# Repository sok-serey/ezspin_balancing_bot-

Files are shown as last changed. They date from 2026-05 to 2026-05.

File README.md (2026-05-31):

# EzSpin Balancing Bot 🤖⚙️

<p align="center">
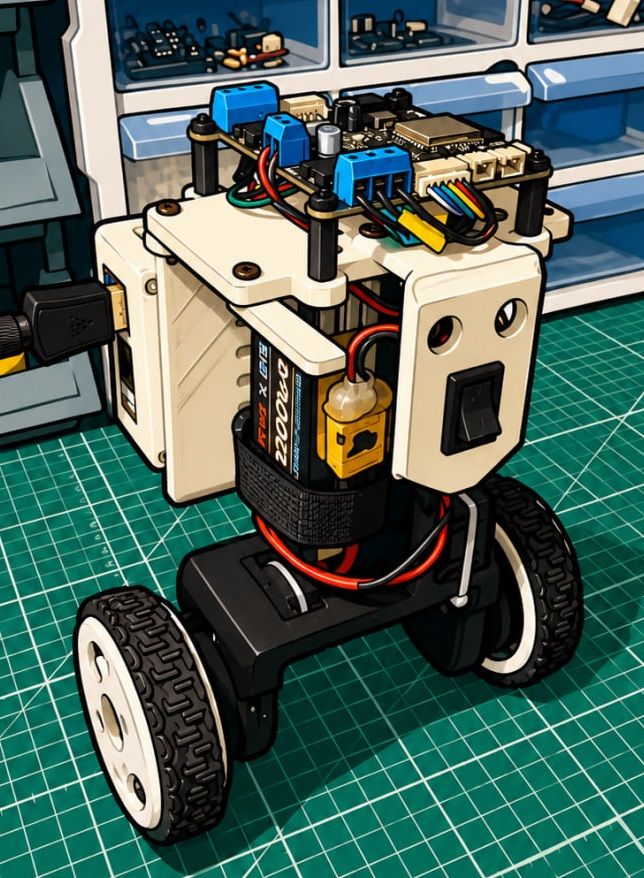
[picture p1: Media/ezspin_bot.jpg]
EzSpin Balancing Bot
  
</p>

## Overview
EzSpin Balancing Bot is a two-wheel self-balancing mobile robot powered by a custom BLDC motor driver.  
The system is designed to control gimbal-type BLDC motors equipped with magnetic encoders via SPI communication.
The custom motor driver also integrates an onboard IMU, providing real-time feedback for closed-loop control and robot stabilization.

---

## Features

- Two-wheel self-balancing mobile platform  
- Onboard IMU sensor for attitude estimation  
- Cascaded PID control architecture  
- BLDC motor control using the SimpleFOC library  
- CAN communication protocol support  
- Supports position, velocity, and torque control modes  
- Multi-platform support: ROS 2, Arduino IDE, MATLAB/Simulink  
- Expandable for autonomous navigation and AI applications  

---

## Robot Overview

### Control Architecture

The EzSpin Balancing Bot maintains stability using a cascade PID control architecture, consisting of an outer velocity control loop and an inner position control loop. The system can be further extended by integrating an Orange Pi 5B running ROS 2, enabling advanced high-level control and communication. A web-based GUI can be developed to send real-time velocity commands, which are then transmitted from the ROS 2 system to the EzSpin controller via the CAN bus protocol for robot motion control and balancing.

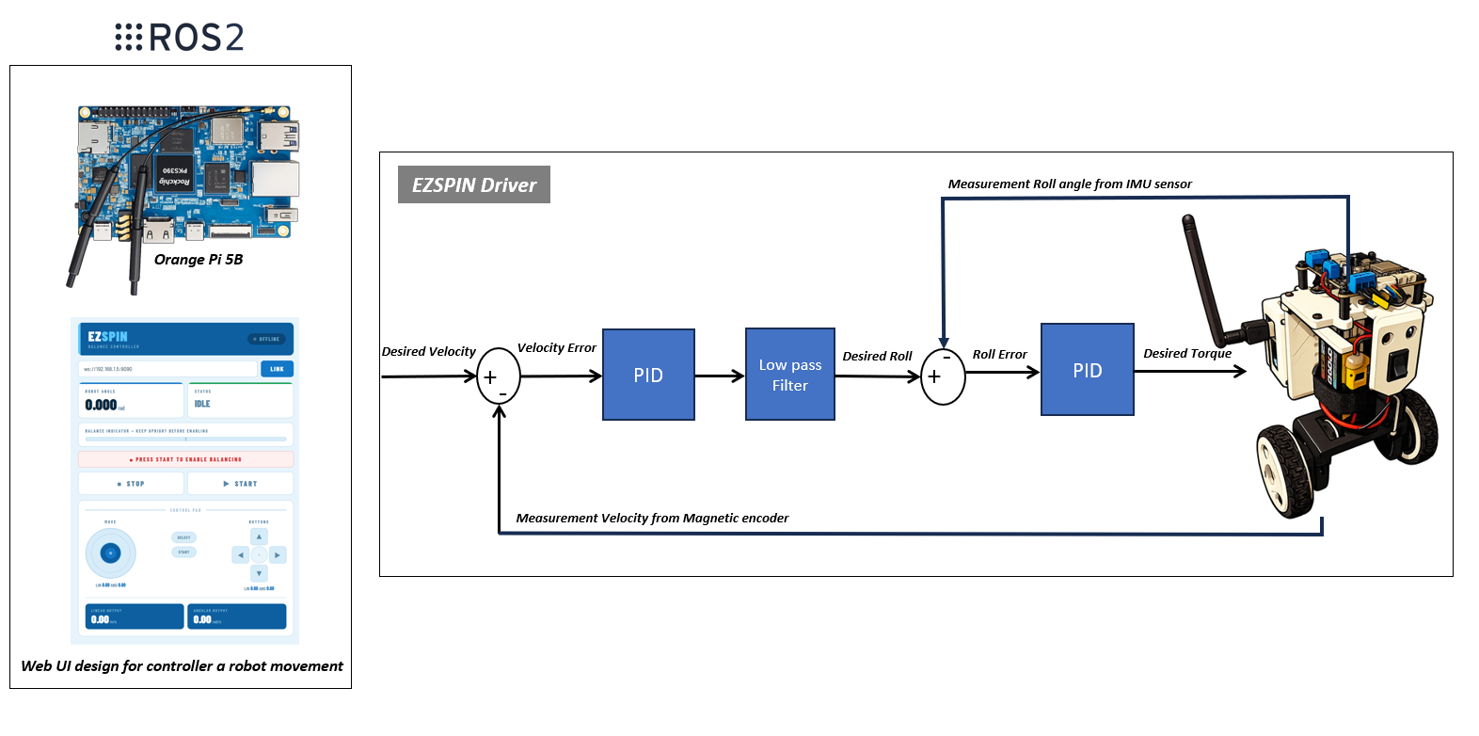
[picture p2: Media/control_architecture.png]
Control Architecture


---

### System Architecture

The EzSpin controller is capable of controlling up to two motors simultaneously while utilizing onboard IMU feedback for real-time stabilization and motion control. The EzSpin board is designed as a ready-to-use solution that supports position, velocity, and torque control modes through both Serial and CAN Bus communication interfaces.

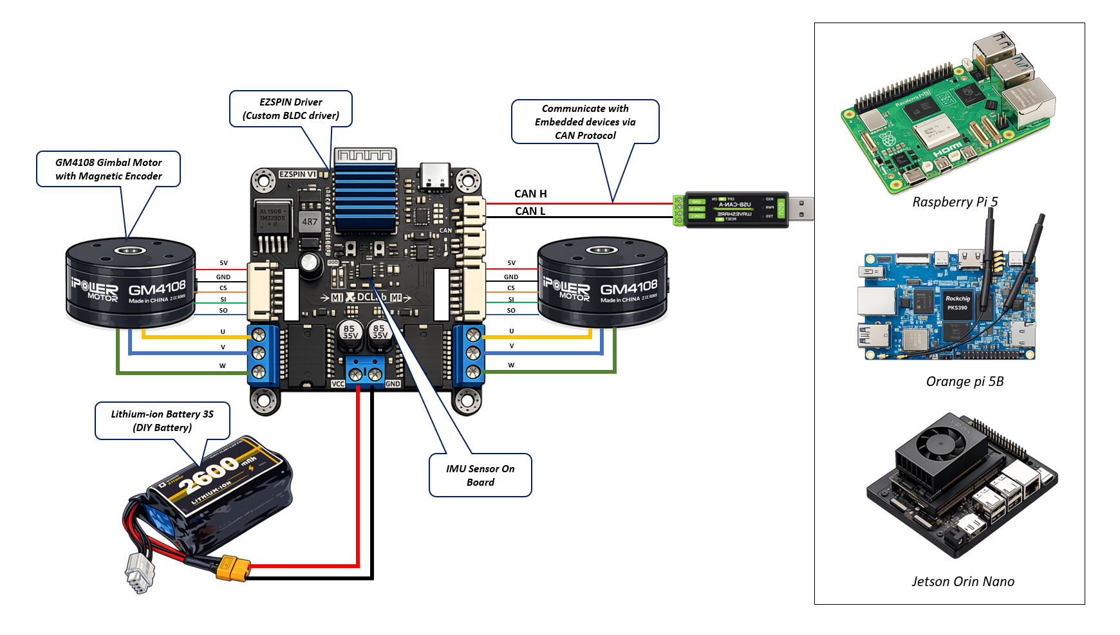
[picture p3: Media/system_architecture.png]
System Architecture


---

### Web GUI

A web-based GUI is developed for real-time control of the EzSpin Bot by sending velocity commands to the robot. The commands are transmitted through the ROS 2 system and communicated to the EzSpin controller via the CAN Bus protocol, enabling responsive and interactive robot operation.

<p align="center">
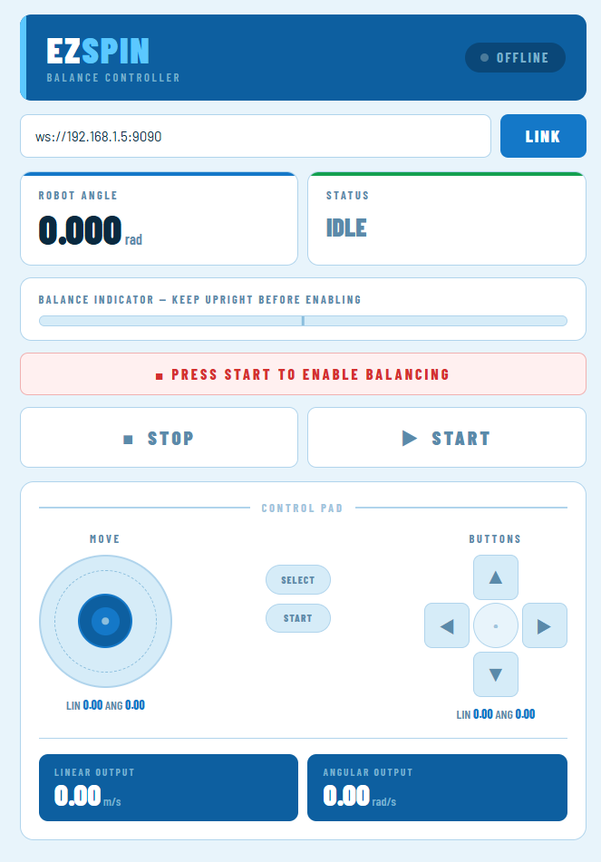
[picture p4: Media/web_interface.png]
Web GUI
  
</p>

## Hardware

### Main Components

| Component | Description |
|---|---|
| MCU | ESP32 |
| IMU | MPU6050 |
| Motor Driver | EzSpin Custom BLDC Driver |
| Motors | GM4108 with Magnetic Encoder |
| Battery | EzSpin DIY Li-ion Battery (3S) |
| Communication  | CAN Bus |

---

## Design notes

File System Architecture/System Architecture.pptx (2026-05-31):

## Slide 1

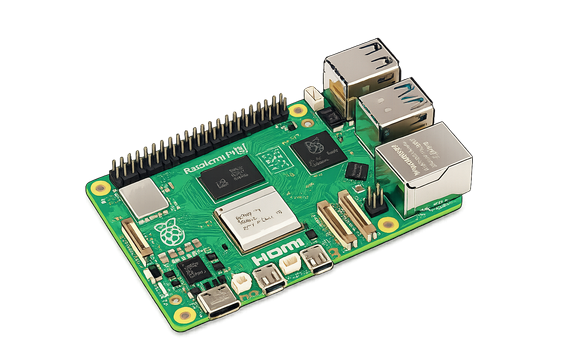
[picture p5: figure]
Cartoon style Raspberry Pi 5 board

Raspberry Pi 5

Orange pi 5B

Jetson Orin Nano

EZSPIN Driver (Custom BLDC driver)

Communicate with Embedded devices via
CAN Protocol

GM4108 Gimbal Motor with Magnetic Encoder

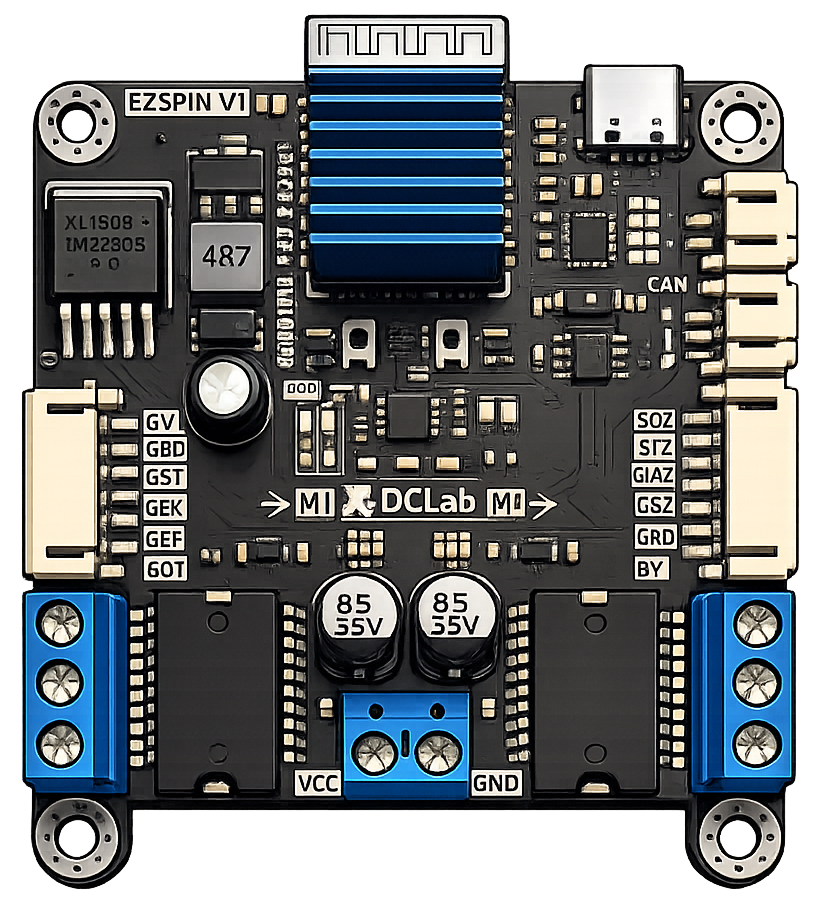
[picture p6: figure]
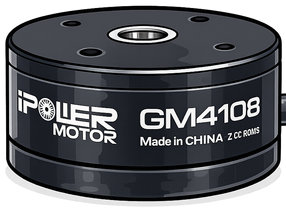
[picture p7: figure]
Cartoon style iPOWER MOTOR GM4108

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
CAN H

CAN L

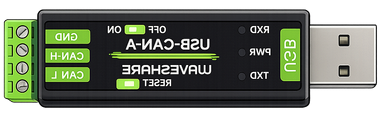
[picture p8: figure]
Cartoon style USB-CAN-A adapter
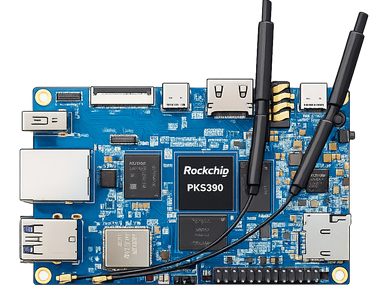
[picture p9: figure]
Cartoon style Rockchip RK3399 development board
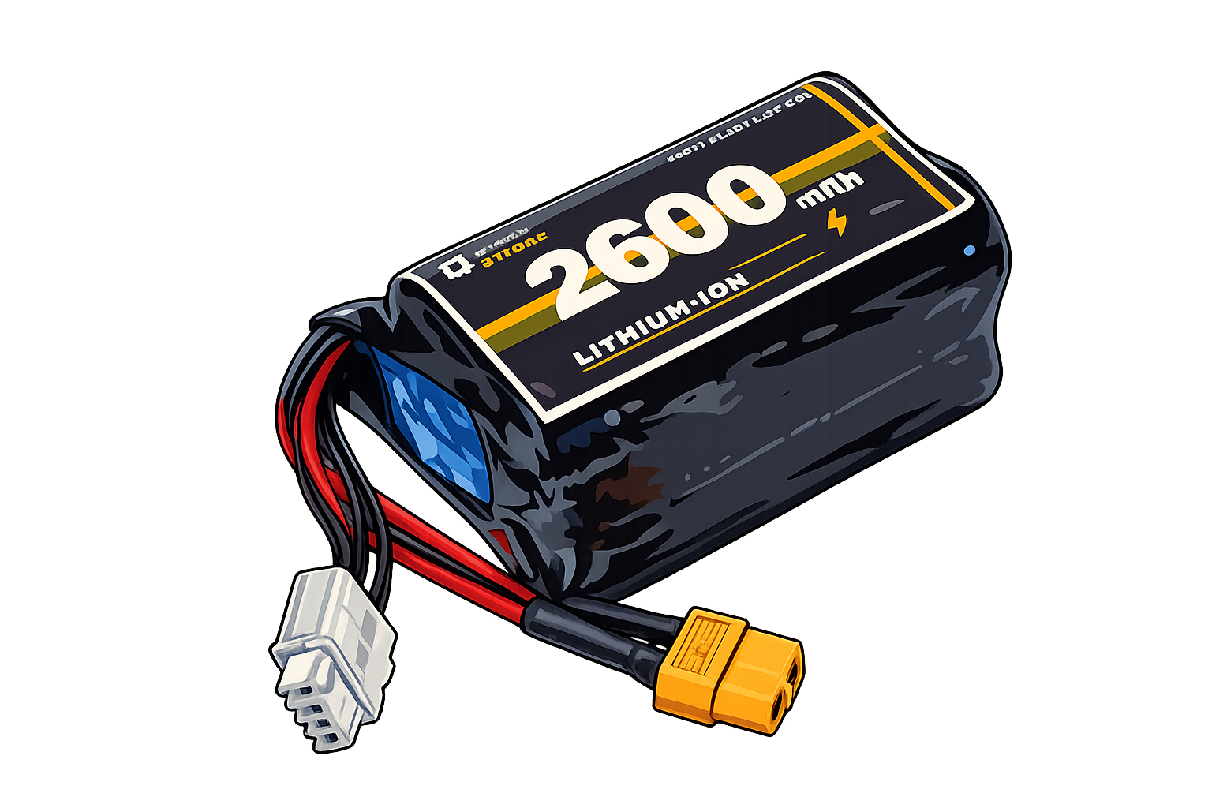
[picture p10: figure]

Lithium-ion Battery 3S
(DIY Battery)

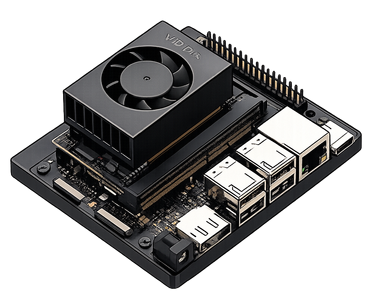
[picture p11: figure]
Cartoon style NVIDIA Jetson Nano board

IMU Sensor On Board

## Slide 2

Web UI design for controller a robot movement

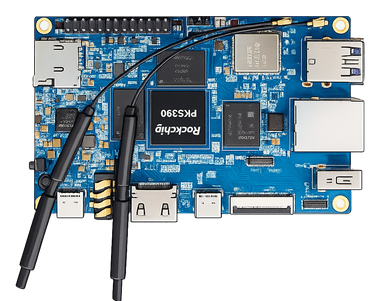
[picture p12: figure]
Cartoon style Rockchip RK3399 development board

Measurement Roll angle from IMU sensor

Desired Velocity

+

Velocity Error

PID

Low pass Filter

Desired Roll

+

Roll Error

PID

Desired Torque

Measurement Velocity from Magnetic encoder

EZSPIN Driver

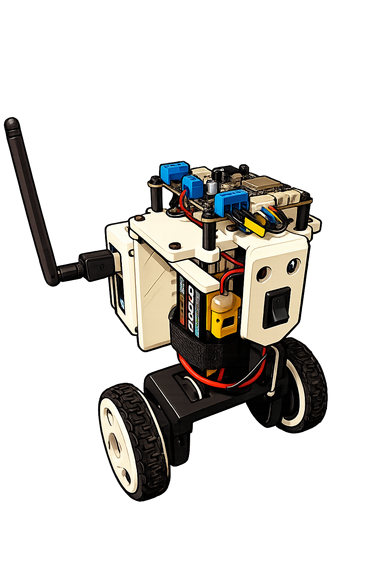
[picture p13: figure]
Self-balancing robot

Orange Pi 5B


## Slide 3

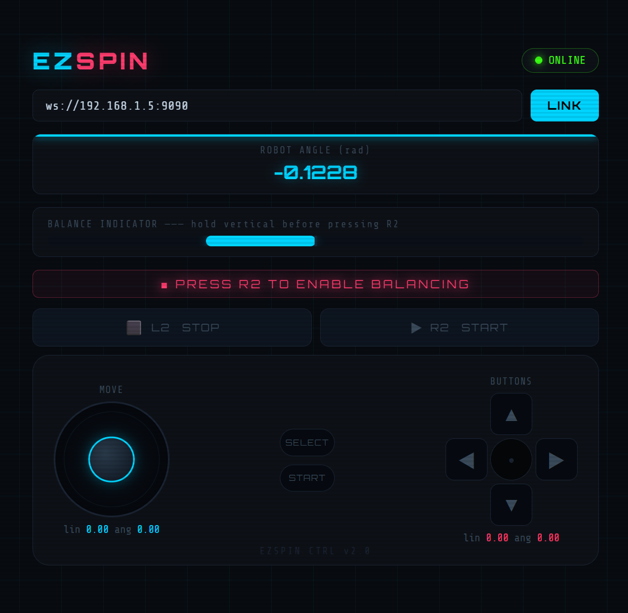
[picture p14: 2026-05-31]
Media/Gamepad_UI.png

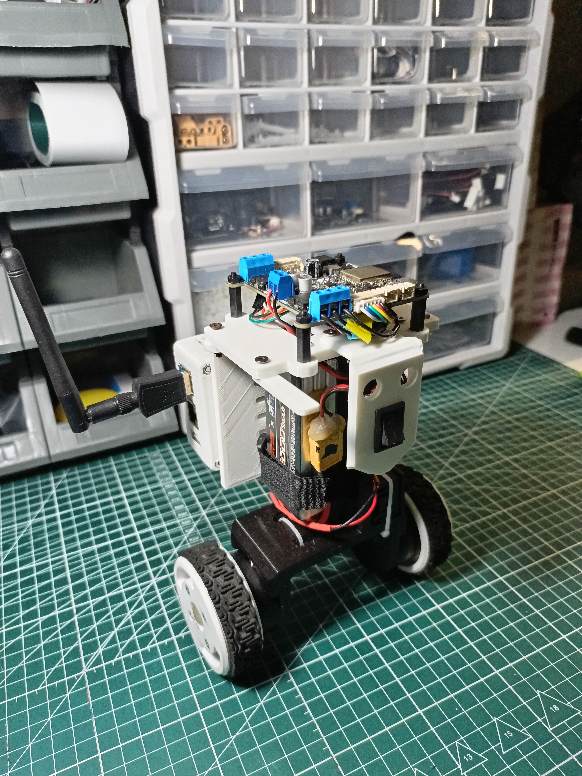
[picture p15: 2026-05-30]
Media/ezspin_balacing_bot_image.jpg

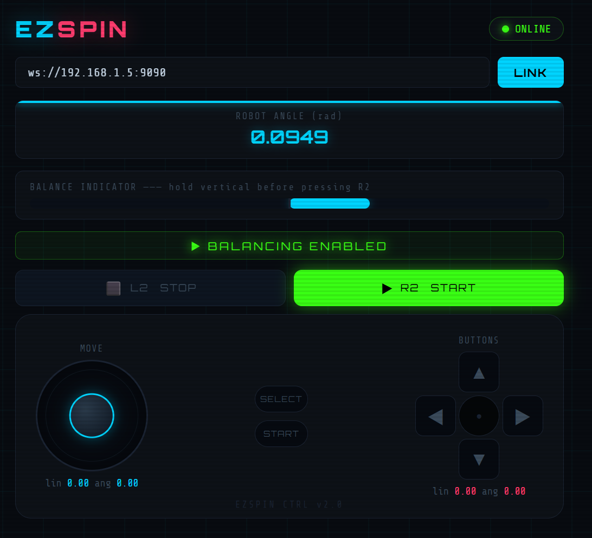
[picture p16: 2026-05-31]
Media/web_interface_1.png

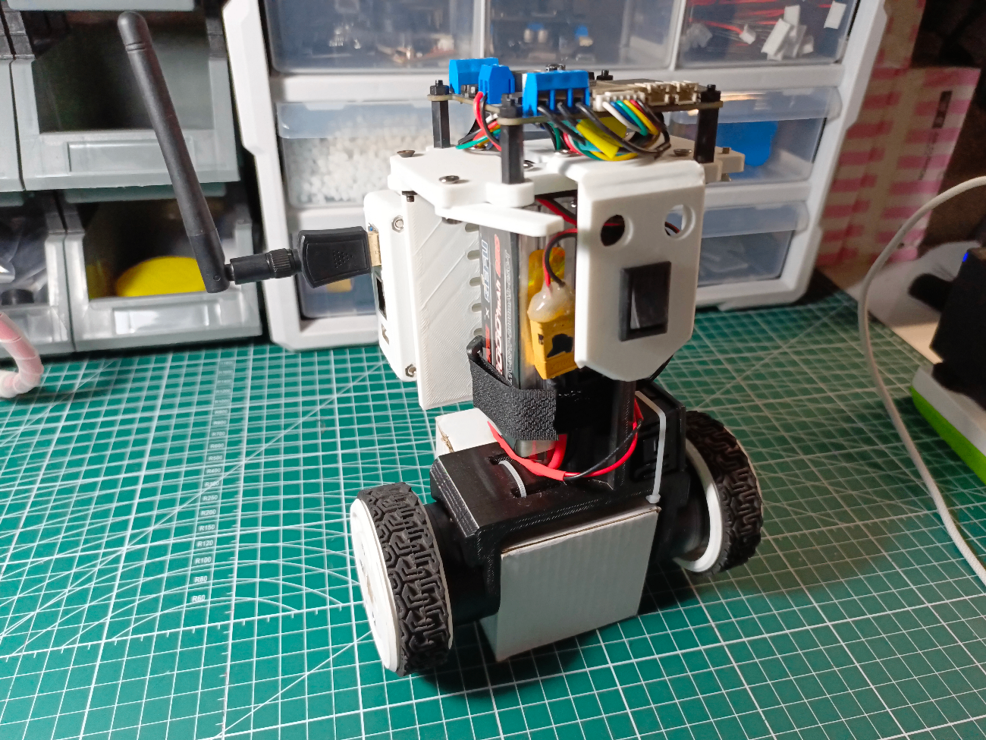
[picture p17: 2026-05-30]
Media/image-CSNY.png

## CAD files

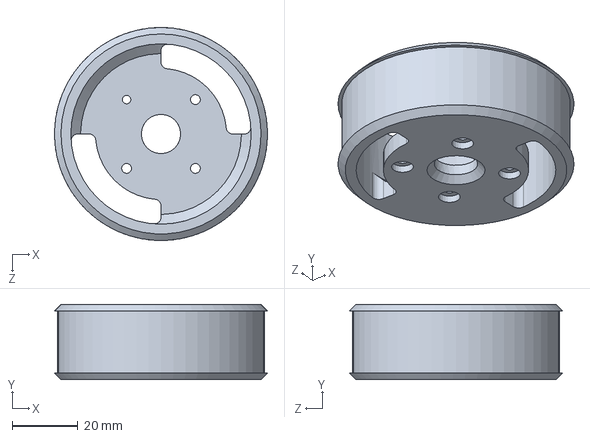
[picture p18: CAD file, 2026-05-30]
CAD/wheel.SLDPRT
65.0 x 23.0 x 65.0 mm

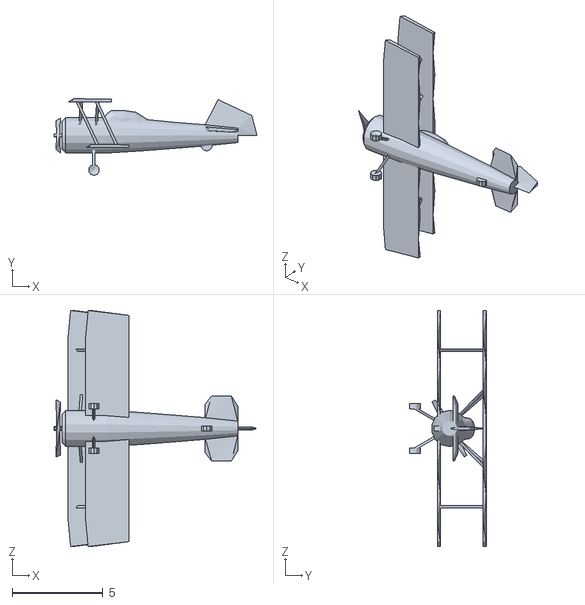
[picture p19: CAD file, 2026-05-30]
ezspin_robot_balancing/src/MPU6050/Examples/MPU6050_DMP6_using_DMP_V6.12/MPUplane/data/biplane.obj
11.2 x 4.23 x 13.0

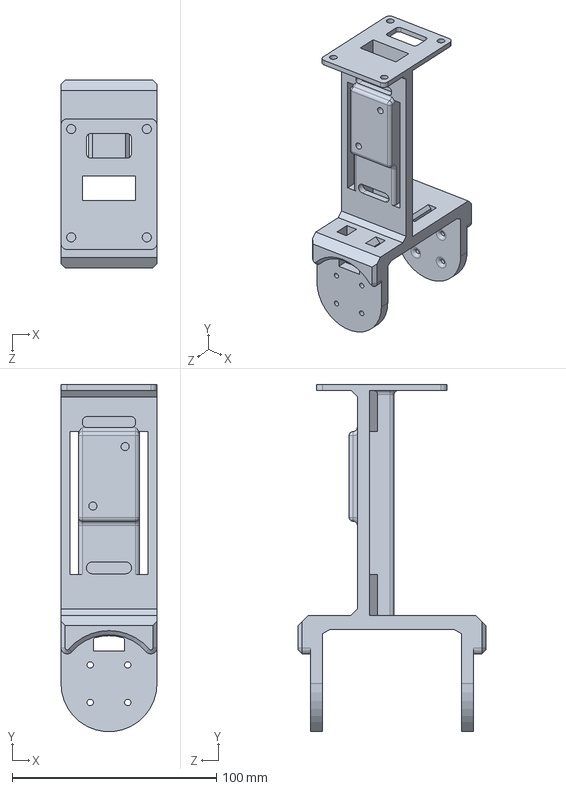
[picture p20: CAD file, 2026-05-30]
CAD/ezspin_bot_body.SLDPRT
47.0 x 169.9 x 92.0 mm

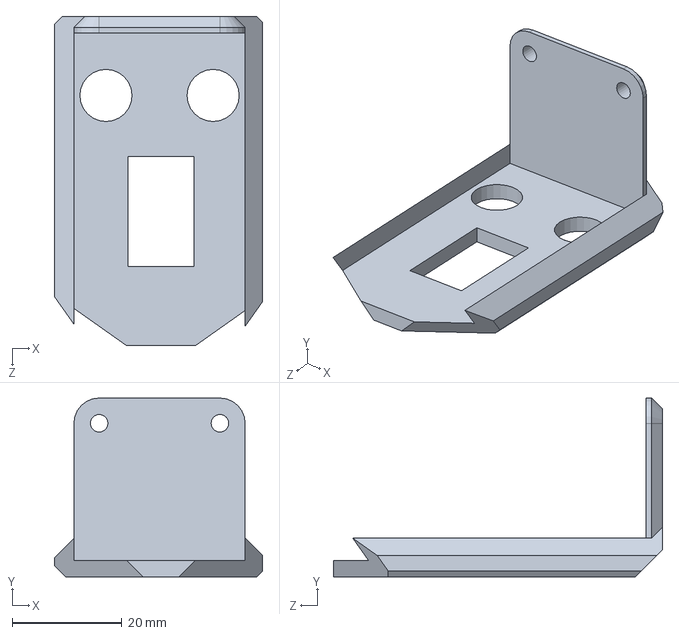
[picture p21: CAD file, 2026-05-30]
CAD/Face.SLDPRT
37.9 x 32.6 x 60.0 mm

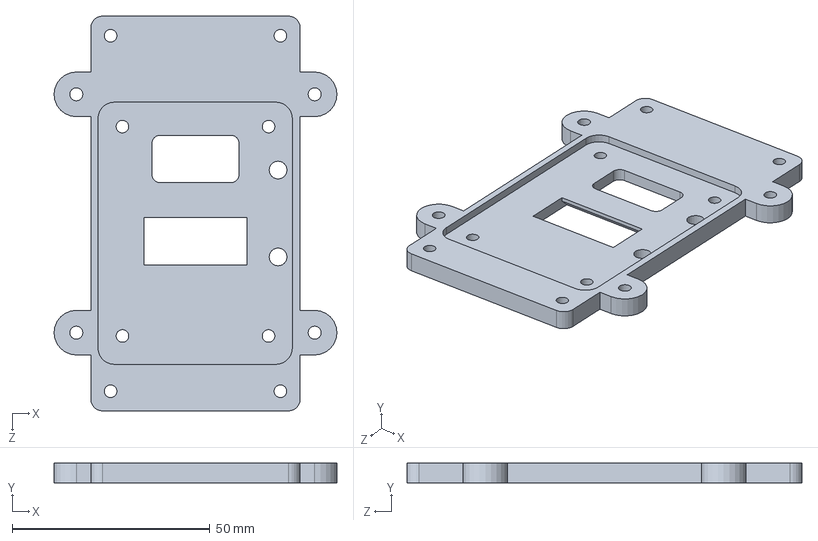
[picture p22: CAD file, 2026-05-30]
CAD/top_mount.SLDPRT
71.6 x 5.00 x 100.0 mm

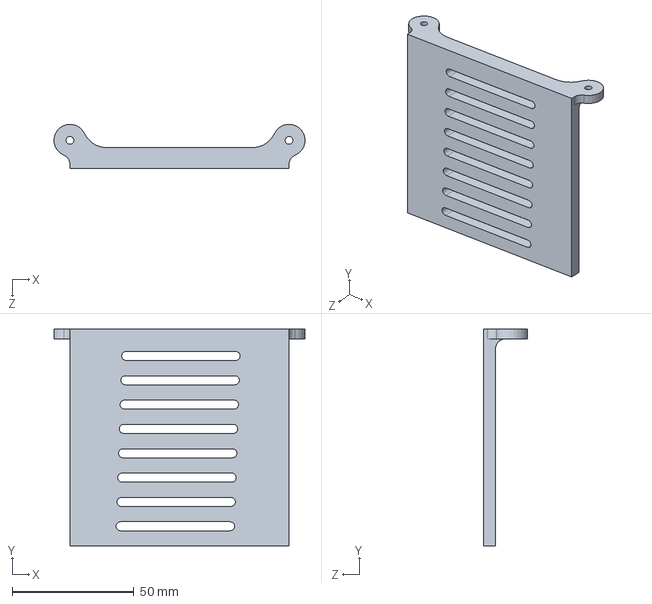
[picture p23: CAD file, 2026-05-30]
CAD/orangepi_attach_frame.SLDPRT
103.1 x 89.0 x 18.2 mm

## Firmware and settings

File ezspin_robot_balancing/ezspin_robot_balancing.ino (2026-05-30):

#include <SimpleFOC.h>
#include "balancer_pinouts.h"
#include "imu.h"
#include "can.h"
#include "BluetoothSerial.h"

BluetoothSerial bluetooth;

// ─────────────────────────────────────────────────────────────────────────────
// BALANCING ENABLE FLAG
// Set via CAN ID 0x010 (defined in can.h):
//   data[0] = 0x01 → enable  (R2 on gamepad)
//   data[0] = 0x00 → disable (L2 on gamepad)
// Serial command: 'E' = enable, 'D' = disable
// ─────────────────────────────────────────────────────────────────────────────
volatile bool balancing_enabled = true;

// ─────────────────────────────────────────────────────────────────────────────
// JOYSTICK cmd_vel — received via CAN ID 0x020
//   cmd_vel_linear  = linear.x  [m/s]  — forward/back
//   cmd_vel_angular = angular.z [rad/s] — turn left/right
//
// How they affect balancing:
//   linear  → added to velocity setpoint in outer loop
//             robot leans forward/back to achieve the commanded speed
//   angular → voltage difference between motors for turning
//             motor1 gets +turn, motor2 gets -turn
// ─────────────────────────────────────────────────────────────────────────────
volatile float cmd_vel_linear  = 0.0f;
volatile float cmd_vel_angular = 0.0f;

// Scale factors — tune to match your robot's speed
#define CMD_VEL_LINEAR_SCALE  15.0f   // 1.0 m/s cmd → 1.0 rad/s velocity setpoint
#define CMD_VEL_ANGULAR_SCALE 1.5f   // 1.0 rad/s cmd → 0.5 V difference between motors

// ─────────────────────────────────────────────────────────────────────────────
// LOW PASS FILTER
// ─────────────────────────────────────────────────────────────────────────────
struct MyLPF {
  float Tf;
  float _y;
  unsigned long _prev_us;

  MyLPF(float tf) : Tf(tf), _y(0.0f), _prev_us(0) {}

  float operator()(float x) {
    unsigned long now = micros();
    float dt = (float)(now - _prev_us) * 1e-6f;
    if (_prev_us == 0 || dt <= 0.0f || dt > 0.5f) {
      _prev_us = now; _y = x; return _y;
    }
    _prev_us = now;
    _y = _y + (x - _y) * dt / (Tf + dt);
    return _y;
  }

  void reset() { _y = 0.0f; _prev_us = 0; }
};

// ─────────────────────────────────────────────────────────────────────────────
// PID CONTROLLER
// Constructor order: (Kp, Ki, Kd, integral_limit, output_limit)
// D term on error — matches SimpleFOC pid.cpp exactly
// ─────────────────────────────────────────────────────────────────────────────
struct MyPID {
  float Kp, Ki, Kd;
  float integral_limit;
  float output_limit;
  float _integral;
  float _prev_error;
  unsigned long _prev_us;

  MyPID(float kp, float ki, float kd, float integ_lim, float out_lim)
    : Kp(kp), Ki(ki), Kd(kd),
      integral_limit(integ_lim), output_limit(out_lim),
      _integral(0.0f), _prev_error(0.0f), _prev_us(0) {}

  float operator()(float error) {
    unsigned long now = micros();
    float dt = (float)(now - _prev_us) * 1e-6f;
    if (_prev_us == 0 || dt <= 0.0f || dt > 0.5f) {
      _prev_us = now; _prev_error = error; return 0.0f;
    }
    _prev_us = now;
    float P = Kp * error;
    _integral += Ki * error * dt;
    _integral  = constrain(_integral, -integral_limit, integral_limit);
    float D = Kd * (error - _prev_error) / dt;
    _prev_error = error;
    return constrain(P + _integral + D, -output_limit, output_limit);
  }

  void reset() {
    _integral = 0.0f; _prev_error = 0.0f; _prev_us = 0;
  }
};

// ─────────────────────────────────────────────────────────────────────────────
// ENCODERS & MOTORS
// NOTE: named 'motor' and 'motor2' to match can.cpp extern
// ─────────────────────────────────────────────────────────────────────────────
MagneticSensorSPI encoder1 = MagneticSensorSPI(AS5147_SPI, 15);
MagneticSensorSPI encoder2 = MagneticSensorSPI(AS5147_SPI, 16);

BLDCMotor motor  = BLDCMotor(11);
BLDCMotor motor2 = BLDCMotor(11);
BLDCDriver3PWM driver1 = BLDCDriver3PWM(MOT1_A, MOT1_B, MOT1_C, MOT1_EN);
BLDCDriver3PWM driver2 = BLDCDriver3PWM(MOT2_A, MOT2_B, MOT2_C, MOT2_EN);

// ─────────────────────────────────────────────────────────────────────────────
// CAN motor targets — defined here, extern'd in can.h
// ─────────────────────────────────────────────────────────────────────────────
float       target_position  = 0.0f;
float       target_velocity  = 0.0f;
float       target_torque    = 0.0f;
MessageType current_mode     = CONTROL_TORQUE;

float       target_position2 = 0.0f;
float       target_velocity2 = 0.0f;
float       target_torque2   = 0.0f;
MessageType current_mode2    = CONTROL_TORQUE;

// ─────────────────────────────────────────────────────────────────────────────
// CONTROLLERS  (Kp, Ki, Kd, integral_limit, output_limit)
// ─────────────────────────────────────────────────────────────────────────────
MyPID pid_stb(18.0f, 60.0f, 0.4f, 50000.0f, 6.0f      );  // inner: full PID
MyPID pid_vel(0.01f, 0.03f, 0.0f, 10000.0f, _PI/10.0f );  // outer: PI

MyLPF lpf_pitch_cmd(0.07f);

float target_pitch = 0.0f;

// ── CAN encoder feedback timing ───────────────────────────────────────────────
static unsigned long lastFeedbackUs = 0;
const  unsigned long FEEDBACK_US    = 10000;  // 100 Hz

// ─────────────────────────────────────────────────────────────────────────────
// STOP MOTORS — zero torque + reset all controllers
// ─────────────────────────────────────────────────────────────────────────────
void stopMotors() {
  motor.target  = 0.0f;
  motor2.target = 0.0f;
  pid_stb.reset();
  pid_vel.reset();
  lpf_pitch_cmd.reset();
  target_pitch = 0.0f;
  Serial.println(F("[BAL] DISABLED — motors zeroed"));
  bluetooth.println(F("[BAL] DISABLED — motors zeroed"));
}

void enableBalancing() {
  pid_stb.reset();
  pid_vel.reset();
  lpf_pitch_cmd.reset();
  target_pitch = 0.0f;
  balancing_enabled = true;
  Serial.println(F("[BAL] ENABLED — balancing started"));
  bluetooth.println(F("[BAL] ENABLED — balancing started"));
}

// ─────────────────────────────────────────────────────────────────────────────
// TUNING  (Serial Monitor or Bluetooth terminal)
//   E       → enable balancing
//   D       → disable balancing
//   SP18    → pid_stb Kp      SI60   → pid_stb Ki     SD0.4  → pid_stb Kd
//   VP0.01  → pid_vel Kp      VI0.03 → pid_vel Ki
//   FC0.07  → lpf_pitch_cmd Tf
//   ?       → print all gains
// ─────────────────────────────────────────────────────────────────────────────
void printGains(Stream& port) {
  port.printf("stb  Kp=%.3f Ki=%.3f Kd=%.4f  integ_lim=%.0f out_lim=%.2f\n",
              pid_stb.Kp, pid_stb.Ki, pid_stb.Kd,
              pid_stb.integral_limit, pid_stb.output_limit);
  port.printf("vel  Kp=%.4f Ki=%.4f  integ_lim=%.0f out_lim=%.4f\n",
              pid_vel.Kp, pid_vel.Ki,
              pid_vel.integral_limit, pid_vel.output_limit);
  port.printf("lpf  cmd_Tf=%.3f\n", lpf_pitch_cmd.Tf);
  port.printf("enabled=%d  lin=%.3f  ang=%.3f\n",
              balancing_enabled, (float)cmd_vel_linear, (float)cmd_vel_angular);
}

void handleTuning(Stream& port) {
  if (!port.available()) return;
  String line = port.readStringUntil('\n');
  line.trim();
  if (line.length() == 0) return;

  if (line.equalsIgnoreCase("E")) { enableBalancing();                       return; }
  if (line.equalsIgnoreCase("D")) { balancing_enabled = false; stopMotors(); return; }
  if (line[0] == '?')            { printGains(Serial); printGains(bluetooth); return; }
  if (line.length() < 3) return;

  char  grp   = toupper(line[0]);
  char  param = toupper(line[1]);
  float val   = line.substring(2).toFloat();

  if      (grp == 'S' && param == 'P') pid_stb.Kp = val;
  else if (grp == 'S' && param == 'I') pid_stb.Ki = val;
  else if (grp == 'S' && param == 'D') pid_stb.Kd = val;
  else if (grp == 'V' && param == 'P') pid_vel.Kp = val;
  else if (grp == 'V' && param == 'I') { pid_vel.Ki = val; pid_vel.reset(); }
  else if (grp == 'F' && param == 'C') lpf_pitch_cmd.Tf = val;

  printGains(Serial);
  printGains(bluetooth);
}

// ─────────────────────────────────────────────────────────────────────────────
// SETUP
// ─────────────────────────────────────────────────────────────────────────────
void setup() {
  Serial.begin(250000);
  bluetooth.begin("FOCBalancer");
  _delay(1000);

  if (!initIMU()) {
    Serial.println(F("IMU error - halting!"));
    while (true);
  }
  _delay(1000);

  initCAN();

  encoder1.init();
  encoder2.init();
  motor.linkSensor(&encoder1);
  motor2.linkSensor(&encoder2);

  driver1.voltage_power_supply = 8;
  driver1.init();
  motor.linkDriver(&driver1);

  driver2.voltage_power_supply = 8;
  driver2.init();
  motor2.linkDriver(&driver2);

  motor.controller  = MotionControlType::torque;
  motor2.controller = MotionControlType::torque;

  motor.useMonitoring(Serial);
  motor2.useMonitoring(Serial);

  motor.init();
  motor2.init();
  motor.initFOC();
  motor2.initFOC();

  Serial.println(F("Ready — send 'E' to enable, 'D' to disable"));
  Serial.println(F("SP/SI/SD  VP/VI  FC  ?=gains"));
  bluetooth.println(F("SP/SI/SD  VP/VI  FC  ?=gains"));
}

// ─────────────────────────────────────────────────────────────────────────────
// MAIN LOOP
// ─────────────────────────────────────────────────────────────────────────────
void loop() {
  // ── FOC — must run as fast as possible ───────────────────────────────────
  motor.loopFOC();
  motor2.loopFOC();

  motor.move();
  motor2.move();

  // ── CAN receive — handles enable + cmd_vel + motor commands ──────────────
  receiveCANMessages();

  // ── IMU — update cache every loop ────────────────────────────────────────
  loopIMU();

  if (cache_valid) {
    cache_valid = false;

    // Always send IMU so OrangePi can monitor angle even when disabled
    sendIMUData();

    if (!balancing_enabled) {
      motor.target  = 0.0f;
      motor2.target = 0.0f;

    } else {
      float pitch   = getPitchIMU();
      float avg_vel = (motor.shaft_velocity + motor2.shaft_velocity) / 2.0f;

      // ── Outer loop: PI velocity → target pitch ──────────────────────────
      // cmd_vel_linear shifts the velocity setpoint:
      //   linear > 0 = move forward → robot leans forward slightly
      //   linear < 0 = move backward → robot leans back slightly
      float vel_setpoint = cmd_vel_linear * CMD_VEL_LINEAR_SCALE;
      float cmd    = pid_vel(avg_vel - vel_setpoint);
      target_pitch = lpf_pitch_cmd(cmd);
      target_pitch = constrain(target_pitch, -0.35f, 0.35f);

      // ── Inner loop: PID pitch error → base voltage ──────────────────────
      float voltage = pid_stb(target_pitch - pitch);

      // ── Turning: add angular difference between motors ──────────────────
      // cmd_vel_angular > 0 = turn left  → motor1 faster, motor2 slower
      // cmd_vel_angular < 0 = turn right → motor2 faster, motor1 slower
      float turn = cmd_vel_angular * CMD_VEL_ANGULAR_SCALE;

      motor.target  = constrain(voltage + turn, -6.0f, 6.0f);
      motor2.target = constrain(voltage - turn, -6.0f, 6.0f);
    }
  }

  // ── CAN encoder feedback at 100 Hz ───────────────────────────────────────
  unsigned long now = micros();
  if (now - lastFeedbackUs >= FEEDBACK_US) {
    lastFeedbackUs = now;
    sendFeedback();
    sendFeedback2();
  }

  // ── Serial / Bluetooth tuning ─────────────────────────────────────────────
  handleTuning(Serial);
  handleTuning(bluetooth);
}

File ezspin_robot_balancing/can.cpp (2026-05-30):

#include "can.h"
#include <Arduino.h>
#include <SimpleFOC.h>
#include "imu.h"

#define CAN_RX_PIN  4
#define CAN_TX_PIN  5

extern BLDCMotor motor;
extern BLDCMotor motor2;
extern float target_position,  target_velocity,  target_torque;
extern float target_position2, target_velocity2, target_torque2;
extern MessageType current_mode, current_mode2;

// ── Runtime configurable CAN IDs & baud ──────────────────────────────────────
uint32_t can_id_motor1_cmd = 1;
uint32_t can_id_motor2_cmd = 2;
uint32_t can_id_motor1_fb  = 0x101;
uint32_t can_id_motor2_fb  = 0x102;
uint32_t can_id_imu        = 200;
uint32_t can_baudrate      = 1000000;

unsigned long lastCANMessageTime  = 0;
unsigned long lastCANMessageTime2 = 0;

// ─────────────────────────────────────────────────────────────────────────────
static bool getBaudConfig(uint32_t baud, twai_timing_config_t* t_config) {
  switch (baud) {
    case 25000:   *t_config = TWAI_TIMING_CONFIG_25KBITS();   return true;
    case 50000:   *t_config = TWAI_TIMING_CONFIG_50KBITS();   return true;
    case 100000:  *t_config = TWAI_TIMING_CONFIG_100KBITS();  return true;
    case 125000:  *t_config = TWAI_TIMING_CONFIG_125KBITS();  return true;
    case 250000:  *t_config = TWAI_TIMING_CONFIG_250KBITS();  return true;
    case 500000:  *t_config = TWAI_TIMING_CONFIG_500KBITS();  return true;
    case 800000:  *t_config = TWAI_TIMING_CONFIG_800KBITS();  return true;
    case 1000000: *t_config = TWAI_TIMING_CONFIG_1MBITS();    return true;
    default:      return false;
  }
}

// ─────────────────────────────────────────────────────────────────────────────
void initCAN() {
  Serial.printf("Starting ESP32 TWAI/CAN @ %lu bps...\n", can_baudrate);

  twai_general_config_t g_config = TWAI_GENERAL_CONFIG_DEFAULT(
    (gpio_num_t)CAN_TX_PIN,
    (gpio_num_t)CAN_RX_PIN,
    TWAI_MODE_NORMAL
  );

  twai_timing_config_t t_config;
  if (!getBaudConfig(can_baudrate, &t_config)) {
    Serial.printf("Invalid baudrate %lu, defaulting to 1Mbps\n", can_baudrate);
    t_config = TWAI_TIMING_CONFIG_1MBITS();
    can_baudrate = 1000000;
  }

  twai_filter_config_t f_config = TWAI_FILTER_CONFIG_ACCEPT_ALL();

  if (twai_driver_install(&g_config, &t_config, &f_config) != ESP_OK) {
    Serial.println("TWAI driver install failed!");
    while (1) delay(1000);
  }
  if (twai_start() != ESP_OK) {
    Serial.println("TWAI start failed!");
    while (1) delay(1000);
  }

  Serial.printf(
    "CAN ready — M1_CMD=%lu M2_CMD=%lu | M1_FB=0x%03lX M2_FB=0x%03lX | IMU=%lu | ENABLE=0x%03X | CMD_VEL=0x%03X\n",
    can_id_motor1_cmd, can_id_motor2_cmd,
    can_id_motor1_fb,  can_id_motor2_fb,
    can_id_imu, CAN_ID_ENABLE, CAN_ID_CMD_VEL
  );
}

// ─────────────────────────────────────────────────────────────────────────────
void restartCAN() {
  twai_stop();
  twai_driver_uninstall();
  delay(100);
  initCAN();
}

// ─────────────────────────────────────────────────────────────────────────────
// receiveCANMessages — single non-blocking receive point for ALL frame types
//
// Frame types handled:
//   CAN_ID_ENABLE  (0x010) — 1 byte  — enable/disable balancing
//   CAN_ID_CMD_VEL (0x020) — 8 bytes — joystick linear.x + angular.z
//   can_id_motor1_cmd (1)  — 5 bytes — motor1 torque/speed/position
//   can_id_motor2_cmd (2)  — 5 bytes — motor2 torque/speed/position
//
// Drains up to 5 frames per call — non-blocking (timeout=0)
// ─────────────────────────────────────────────────────────────────────────────
void receiveCANMessages() {
  twai_message_t rxMsg;

  for (int i = 0; i < 5; i++) {
    if (twai_receive(&rxMsg, 0) != ESP_OK) break;

    // ── Enable / disable ──────────────────────────────────────────────────
    if (rxMsg.identifier == CAN_ID_ENABLE && rxMsg.data_length_code >= 1) {
      if (rxMsg.data[0] == 0x01 && !balancing_enabled) {
        enableBalancing();
      } else if (rxMsg.data[0] == 0x00 && balancing_enabled) {
        balancing_enabled = false;
        stopMotors();
      }
      continue;
    }

    // ── cmd_vel from joystick ─────────────────────────────────────────────
    // data[0..3] = linear.x  (float) — forward/back m/s
    // data[4..7] = angular.z (float) — turn rad/s
    if (rxMsg.identifier == CAN_ID_CMD_VEL && rxMsg.data_length_code == 8) {
      memcpy((void*)&cmd_vel_linear,  &rxMsg.data[0], sizeof(float));
      memcpy((void*)&cmd_vel_angular, &rxMsg.data[4], sizeof(float));
      continue;
    }

    // ── Motor commands — must be exactly 5 bytes ──────────────────────────
    if (rxMsg.data_length_code != 5) continue;

    uint8_t received_mode = rxMsg.data[0];
    float   new_target;
    memcpy(&new_target, &rxMsg.data[1], sizeof(float));

    // Motor 1
    if (rxMsg.identifier == can_id_motor1_cmd) {
      lastCANMessageTime = millis();
      if (received_mode == CONTROL_POSITION && current_mode != CONTROL_POSITION) {
        motor.controller = MotionControlType::angle;
        current_mode = CONTROL_POSITION; target_position = new_target;
      } else if (received_mode == CONTROL_SPEED && current_mode != CONTROL_SPEED) {
        motor.controller = MotionControlType::velocity;
        current_mode = CONTROL_SPEED; target_velocity = new_target;
      } else if (received_mode == CONTROL_TORQUE && current_mode != CONTROL_TORQUE) {
        motor.controller = MotionControlType::torque;
        current_mode = CONTROL_TORQUE; target_torque = new_target;
      } else {
        float& t = (current_mode == CONTROL_POSITION) ? target_position :
                   (current_mode == CONTROL_SPEED)    ? target_velocity : target_torque;
        if (fabs(new_target - t) > 0.05f) t = new_target;
      }
    }

    // Motor 2
    else if (rxMsg.identifier == can_id_motor2_cmd) {
      lastCANMessageTime2 = millis();
      if (received_mode == CONTROL_POSITION && current_mode2 != CONTROL_POSITION) {
        motor2.controller = MotionControlType::angle;
        current_mode2 = CONTROL_POSITION; target_position2 = new_target;
      } else if (received_mode == CONTROL_SPEED && current_mode2 != CONTROL_SPEED) {
        motor2.controller = MotionControlType::velocity;
        current_mode2 = CONTROL_SPEED; target_velocity2 = new_target;
      } else if (received_mode == CONTROL_TORQUE && current_mode2 != CONTROL_TORQUE) {
        motor2.controller = MotionControlType::torque;
        current_mode2 = CONTROL_TORQUE; target_torque2 = new_target;
      } else {
        float& t = (current_mode2 == CONTROL_POSITION) ? target_position2 :
                   (current_mode2 == CONTROL_SPEED)    ? target_velocity2 : target_torque2;
        if (fabs(new_target - t) > 0.05f) t = new_target;
      }
    }
  }
}
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

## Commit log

2026-05-30 add cad
    [Face.SLDPRT, ezspin_bot_body.SLDPRT, orangepi_attach_frame.SLDPRT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]
2026-05-30 add ezspin code
    [biplane.obj]
